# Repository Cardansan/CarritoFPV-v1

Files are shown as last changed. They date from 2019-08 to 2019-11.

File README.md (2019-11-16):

# CarritoFPV-v1
## ESP-8266
Usado para controlar los motores gracias al shield de NodeMCU. Éste es el Punto de Acceso WiFI, el ESP32 se conecta también aquí. IMPORTANTE: el shield es compatible con la tarjeta V2 (ESP-12E o NodeMCU 1.0).

Shield + ESP: https://articulo.mercadolibre.com.mx/MLM-702378293-modulos-shield-expansion-io-motores-puente-h-l293d-nodemcu-_JM

ESP: https://articulo.mercadolibre.com.mx/MLM-588747283-modulo-nodemcu-lua-wifi-esp8266-v2-cdmex-_JM?quantity=1

Shield: https://articulo.mercadolibre.com.mx/MLM-590470210-shield-expansion-io-motores-puente-h-l293d-nodemcu-esp8266-_JM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

## ESP32-CAM
https://articulo.mercadolibre.com.mx/MLM-671140521-esp32cam-modulo-esp32-cam-camara-ov2640-arduino-wifi-ble-_JM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

Hubieron detalles subiendo el código desde Platformio, con el IDE de Arduino sucedió sin incidentes. Recordar conectar como en el enlace de tutorial de ejemplo y oprimir el botón de reset de la placa cuando sea necesario. 

Tutorial ejemplo: https://randomnerdtutorials.com/esp32-cam-video-streaming-web-server-camera-home-assistant/

Programar con Arduino como FTDI: https://www.youtube.com/watch?v=a_PxAT8M-58

Troubleshooting: https://randomnerdtutorials.com/esp32-cam-troubleshooting-guide/

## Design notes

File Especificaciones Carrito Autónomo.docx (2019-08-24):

# Carrito Autónomo

# Introducción

La estructura está formada por palitos de bambú (⌀3 mm) y conectores impresos en 3D (PLA).

Se utiliza la misma base del Carrito Autónomo pero con diferentes componentes electrónicos para funcionar como vehículo de radiocontrol y FPV (first person view).

The structure is made of bamboo sticks (⌀3 mm) and 3D printed parts (PLA).

Autonomous toy car

It's controlled by Node MCU 1.0 (aka ESP-12E Dev Kit). It uses an ultrasonic distance sensor (US-100) attached to a servo (SG-90) so it can detect obstacles on the sides. A second servo moves the front wheels and a steering wheel to give it a realistic look. The microcontroller is connected to ESP-12E Motor Shield, the shield drives two gear motors.

FPV toy car

The ultrasonic sensor is replaced by a mini camera, and a RC receiver is added. Speed, steering and camera position is controlled by a RC transmitter.

Se presentará en la Semana del Emprendedor 2018.

Se usará en el Curso de Mecatrónica 2018.

# Partes

## Lista resumida

11 Nylon-insert lock nuts M3

16 Flat washers M3 (⌀external 7 mm, ⌀internal 3.2 mm, thickness 0.5 mm)

13 Bolts M3 (various lengths)

4 Screw M2x10 (or similar)

4 Screw to mount servos
18 Bamboo sticks ⌀3 mm (various lengths)

2 Gear motors

2 Micro servos (SG90)

25 3D printed parts [Autonomous version]

26 3D printed parts [FPV version]

1 Ultrasonic distance sensor (US-100, 3.3 V) [Autonomous version]

1 Mini camera (Eachine TX02 NTSC) [FPV version]

1 NodeMCU

1 RC Receiver and transmitter [FPV version]

Cables

Cyanoacrylate

Piezas 18A y 18B son para diferentes tamaños de sensores ultrasónicos.

Piezas 21A y 21B son para diferentes alturas de la cámara.

Parts 18A and 18B are for different sizes of ultrasonic sensors.

Part 20 only used in FPV version.

Parts 21A and 21B are for different camera heights.

## Longitudes de palitos

2x 15 mm

2x 70 mm

1x 80 mm

7x 90 mm

2x 100 mm

2x 130 mm

2x 180 mm

## Longitudes de tornillos

4x Bolt M3 x 15

4x Bolt M3 x 30

3x Bolt M3 x 20 ___

2x Bolt M3 x 5

4x Screw to mount servos (they come with SG90 servos)

4x Screw M2x10 (they hold horns to servos and wheels to gear motors)

## ESP-12E DevKit V2

También llamado NodeMCU 1.0

Al programar con Arduino IDE, es más fácil utilizar utilizar los nombres de pines D1 a D8

https://iotbytes.wordpress.com/nodemcu-pinout/

https://www.teachmemicro.com/nodemcu-pinout/

PWM con 1023 valores.

## ESP-12E Motor Shield

Utiliza el controlador L293DD

## Sensor de distancia ultrasónico US-100

Voltaje de alimentación 2.4V - 5.5V

Dos modos de funcionamiento: Serial y Pulso

El modo se selecciona con un jumper.

En modo Serial envía la lectura de distancia en formato de 2 bytes. En este modo también puede medir temperatura.

En modo Pulso envía un pulso con ancho proporcional a la distancia (como el HC-SR04).

En las pruebas realizadas la distancia máxima medible es 2 m (¿se puede configurar?)

https://www.bananarobotics.com/shop/US-100-Ultrasonic-Distance-Sensor-Module

http://tinkbox.ph/sites/mytinkbox.com/files/downloads/US_100_ULTRASONIC_SENSOR_MODULE.pdf

## Servomotor SG90

Servomotor muy popular. Marca TENSTAR ROBOT.

# Cómo programar ESP-12E con Arduino IDE

## Instalar Núcleo

Abrir Arduino IDE

Menú File → Preferences

Escribir la siguiente dirección en “Additional Boards Manager URLs”

http://arduino.esp8266.com/stable/package_esp8266com_index.json

Menú Tools → Board → Boards Manager

Escribe “esp” en el cuadro de búsqueda

Instala “esp8266 by ESP8266 Community”

Documentación: https://arduino-esp8266.readthedocs.io/en/latest/index.html

## Pinout

Se puede usar el número de GPIO en el código, pero es más fácil usar el nombre que aparece impreso en la placa (D0, D1, D2, …)

https://iotbytes.wordpress.com/nodemcu-pinout/

## PWM

Por defecto las salidas PWM pueden usar ciclos de trabajo de 0 a 1023.

Se puede configurar la frecuencia de PWM (1 a 1000 kHz) y el rango de ciclo de trabajo.

http://www.electronicwings.com/nodemcu/nodemcu-pwm-with-arduino-ide

# Versión modificada

Con cámara y receptor RC (radio-control).

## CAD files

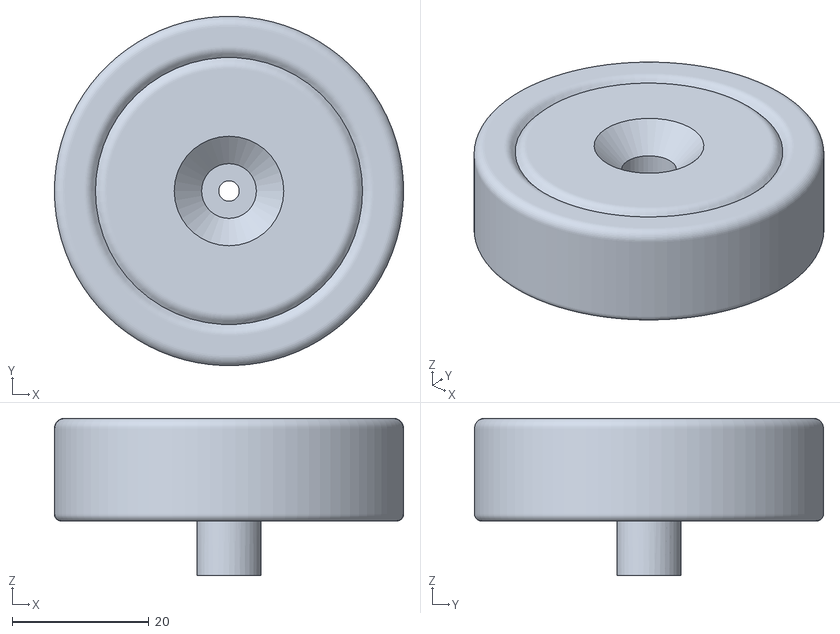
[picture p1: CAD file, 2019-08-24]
Piezas Impresión 3D/Filamento Flexible/13.STL
51.0 x 51.0 x 23.0

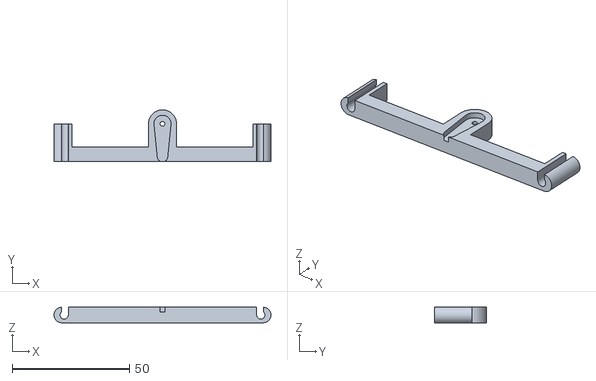
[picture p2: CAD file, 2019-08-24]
Piezas Impresión 3D/Imprimir Blanco/20.STL
92.7 x 22.0 x 6.70

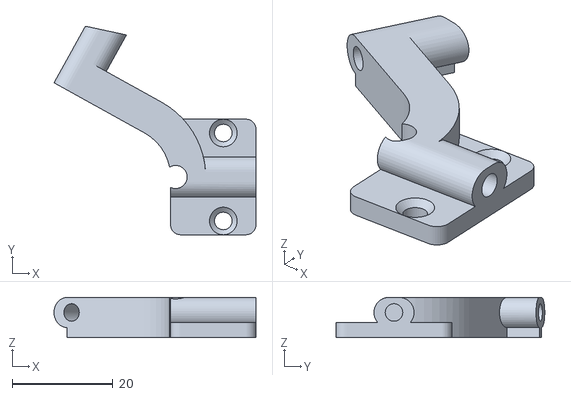
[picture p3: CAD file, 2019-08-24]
Piezas Impresión 3D/Imprimir Negro/1R.STL
40.2 x 41.5 x 8.00

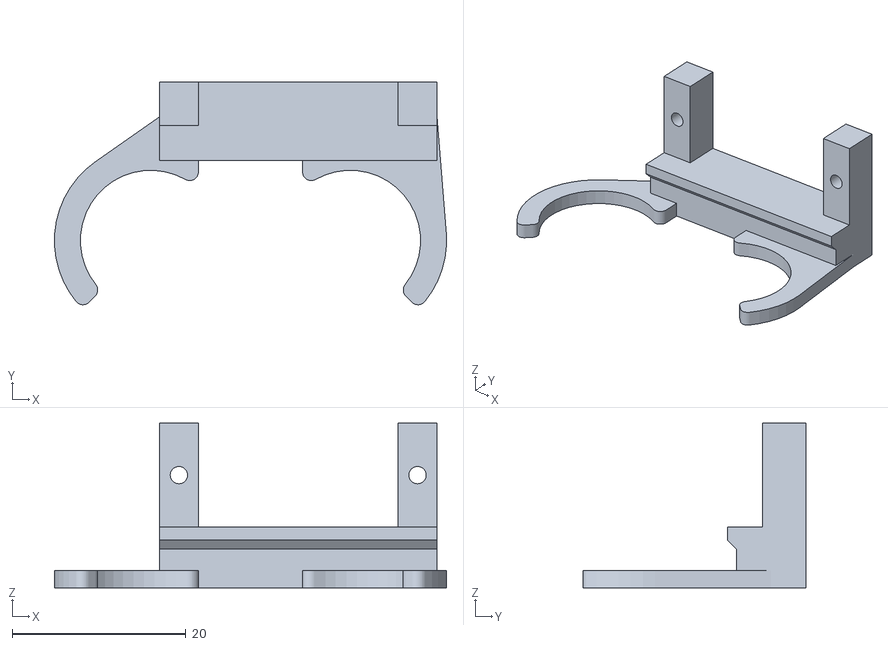
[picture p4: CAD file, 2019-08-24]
Piezas Impresión 3D/Imprimir Negro/Éstas aún no imprimir/18B.STL
45.2 x 25.6 x 19.0

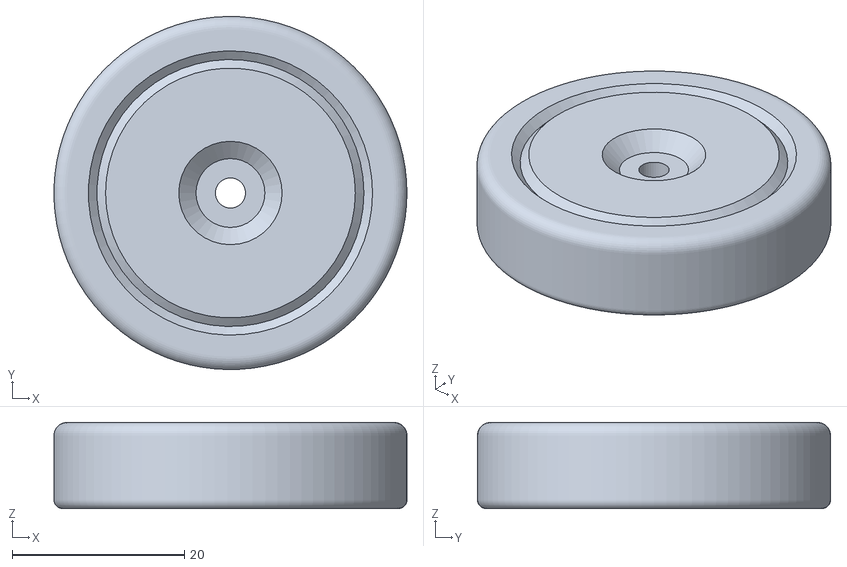
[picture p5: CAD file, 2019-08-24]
Piezas Impresión 3D/Filamento Flexible/12.STL
41.0 x 41.0 x 10.0

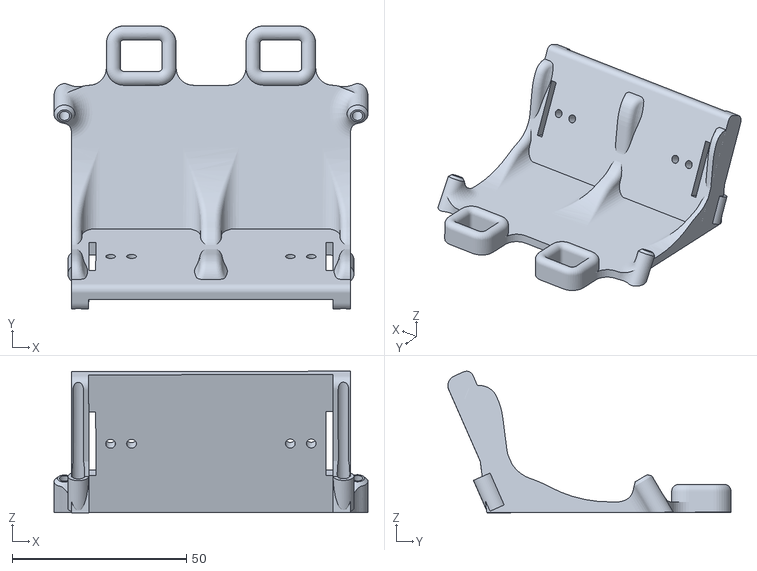
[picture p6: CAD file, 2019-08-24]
Piezas Impresión 3D/Imprimir Blanco/2.STL
90.0 x 81.1 x 40.6

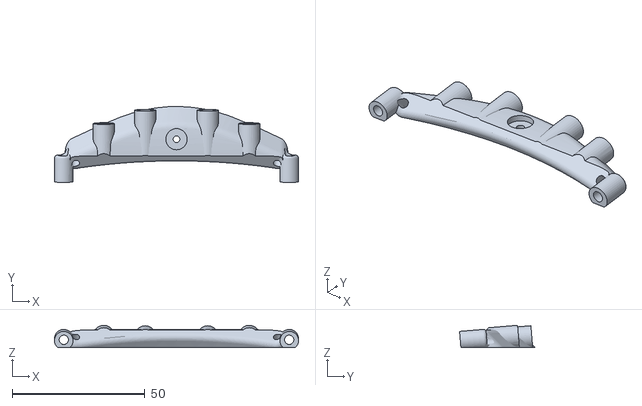
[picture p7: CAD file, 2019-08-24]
Piezas Impresión 3D/Imprimir Negro/5.STL
92.0 x 28.6 x 8.47

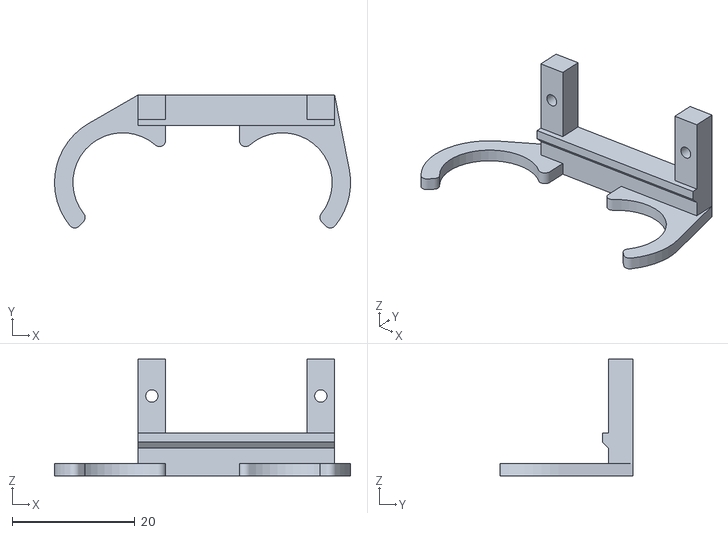
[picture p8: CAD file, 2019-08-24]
Piezas Impresión 3D/Imprimir Negro/Éstas aún no imprimir/18A.STL
48.2 x 21.6 x 19.0

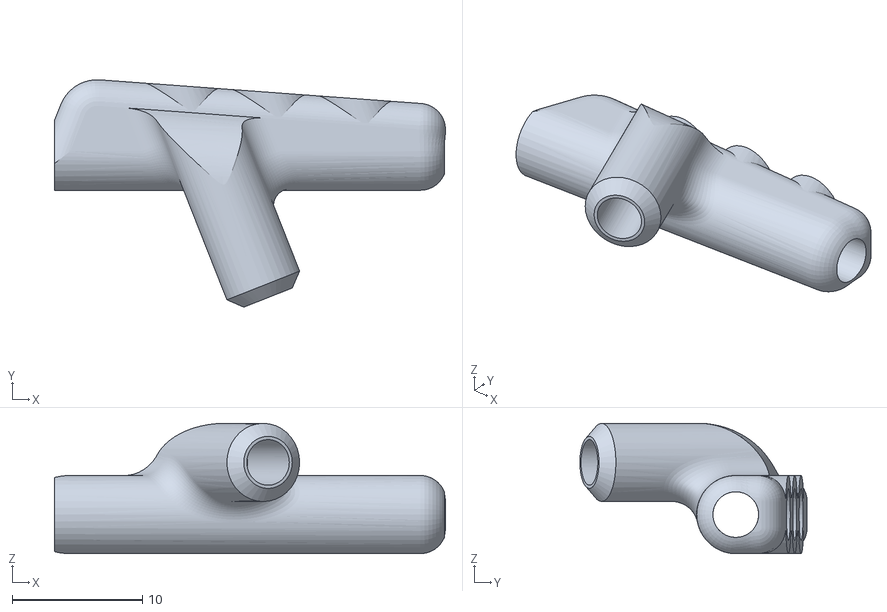
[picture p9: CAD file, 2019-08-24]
Piezas Impresión 3D/Imprimir Negro/3.STL
30.0 x 17.4 x 10.0

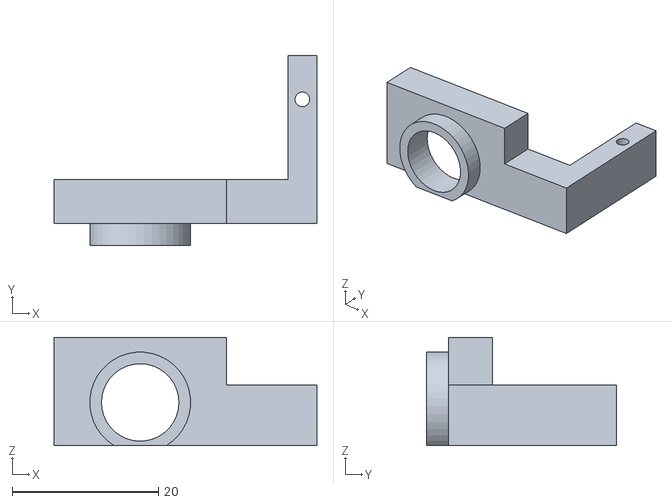
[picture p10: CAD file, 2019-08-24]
Piezas Impresión 3D/Imprimir Negro/Éstas aún no imprimir/21A.STL
36.0 x 26.0 x 14.8

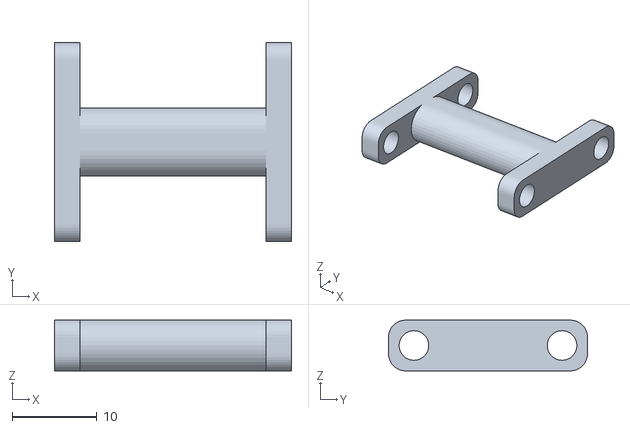
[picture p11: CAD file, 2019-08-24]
Piezas Impresión 3D/Imprimir Negro/0.STL
28.0 x 23.5 x 6.00

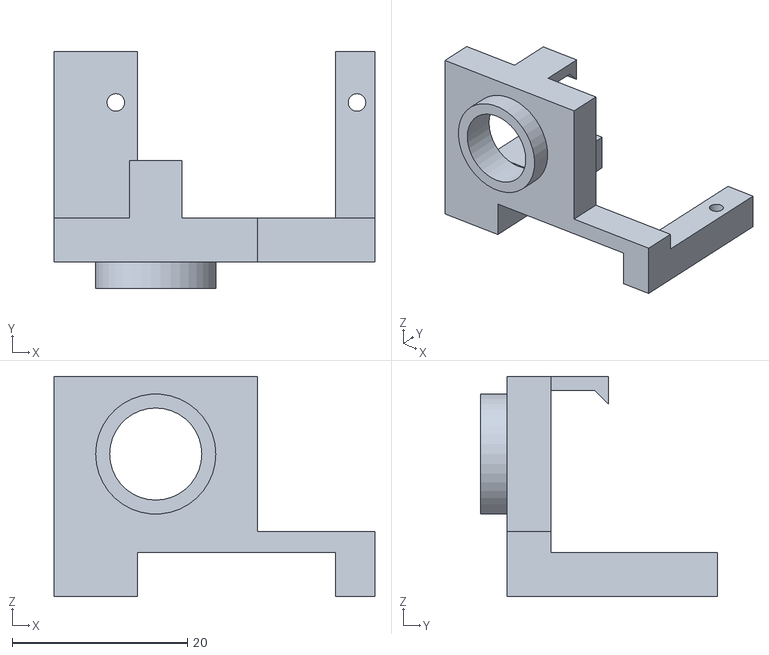
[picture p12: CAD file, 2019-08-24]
Piezas Impresión 3D/Imprimir Negro/Éstas aún no imprimir/21B.STL
36.6 x 27.0 x 25.1

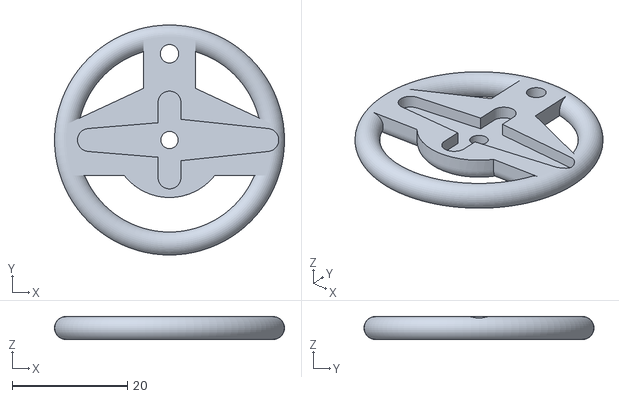
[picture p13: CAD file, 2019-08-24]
Piezas Impresión 3D/Imprimir Negro/17.STL
40.0 x 40.0 x 4.00

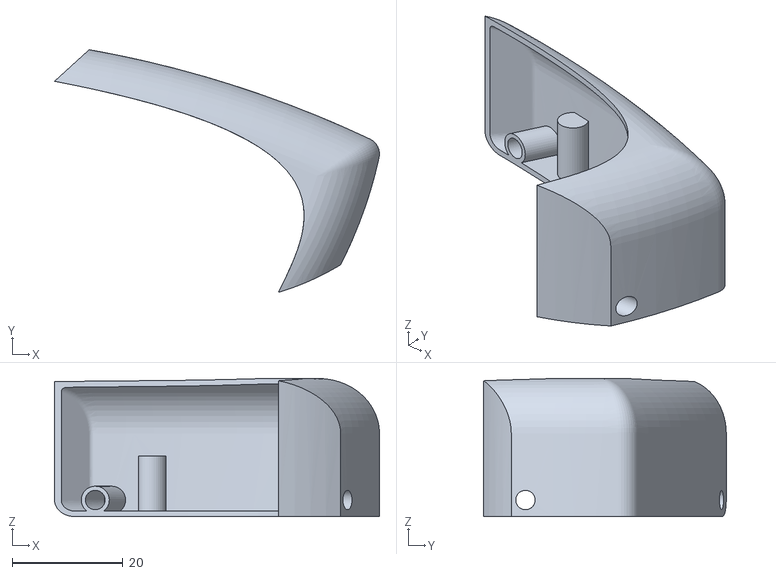
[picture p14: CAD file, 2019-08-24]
Piezas Impresión 3D/Imprimir Negro/8.STL
58.8 x 43.9 x 25.0

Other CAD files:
Piezas Impresión 3D/Imprimir Negro/4.STL
Piezas Impresión 3D/Imprimir Negro/14.STL
Piezas Impresión 3D/Imprimir Negro/1L.STL
Piezas Impresión 3D/Imprimir Negro/9.STL
Piezas Impresión 3D/Imprimir Negro/10.STL
Piezas Impresión 3D/Imprimir Negro/19.STL
Piezas Impresión 3D/Imprimir Negro/6.STL
Piezas Impresión 3D/Imprimir Negro/7.STL

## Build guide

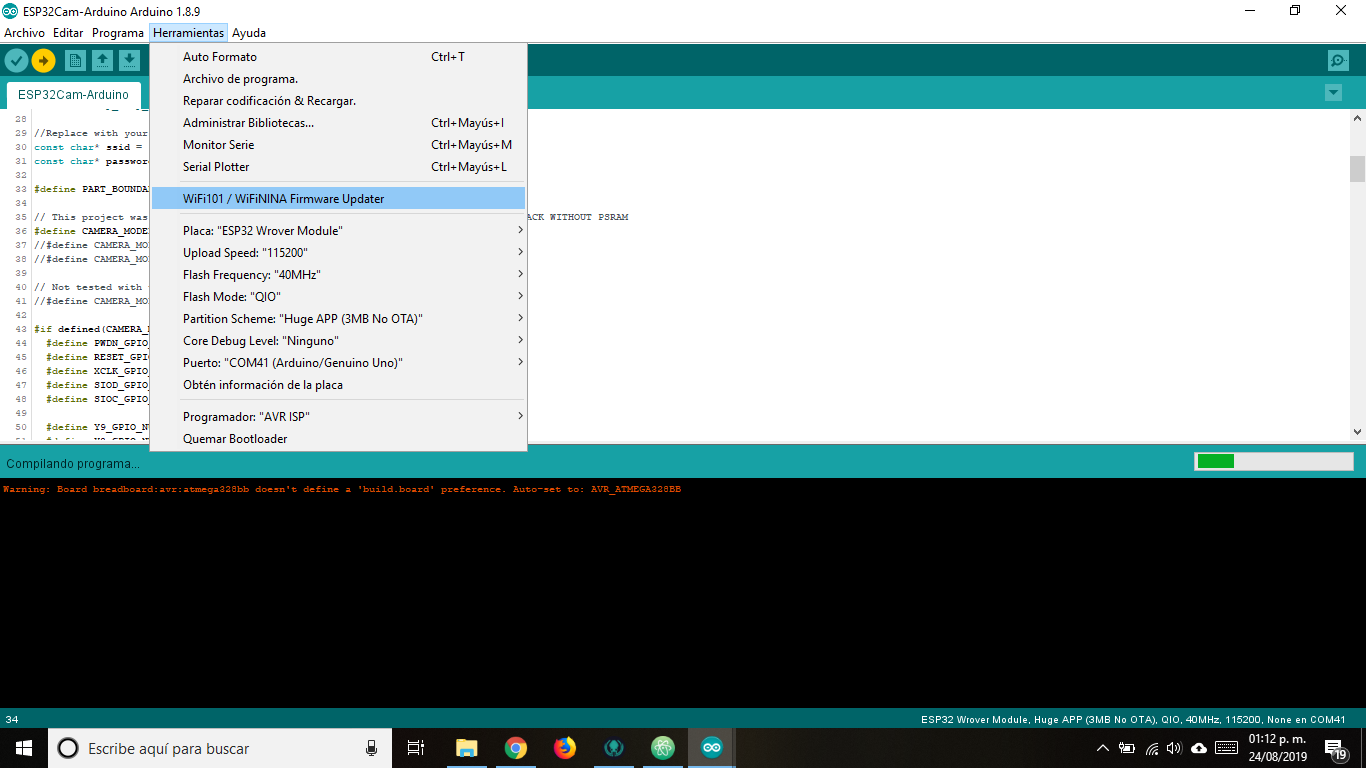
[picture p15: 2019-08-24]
ESP32CAMsetup.png

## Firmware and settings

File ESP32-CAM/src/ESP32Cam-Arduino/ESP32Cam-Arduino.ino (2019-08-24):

/*********
  Rui Santos
  Complete project details at https://RandomNerdTutorials.com
  
  IMPORTANT!!! 
   - Select Board "ESP32 Wrover Module"
   - Select the Partion Scheme "Huge APP (3MB No OTA)
   - GPIO 0 must be connected to GND to upload a sketch
   - After connecting GPIO 0 to GND, press the ESP32-CAM on-board RESET button to put your board in flashing mode
  
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
  The above copyright notice and this permission notice shall be included in all
  copies or substantial portions of the Software.
*********/

#include "esp_camera.h"
#include <WiFi.h>
#include "esp_timer.h"
#include "img_converters.h"
#include "Arduino.h"
#include "fb_gfx.h"
#include "soc/soc.h" //disable brownout problems
#include "soc/rtc_cntl_reg.h"  //disable brownout problems
#include "dl_lib.h"
#include "esp_http_server.h"

//Replace with your network credentials
const char* ssid = "CarroFPV";
const char* password = "science_7425";

#define PART_BOUNDARY "123456789000000000000987654321"

// This project was tested with the AI Thinker Model, M5STACK PSRAM Model and M5STACK WITHOUT PSRAM
#define CAMERA_MODEL_AI_THINKER
//#define CAMERA_MODEL_M5STACK_PSRAM
//#define CAMERA_MODEL_M5STACK_WITHOUT_PSRAM

// Not tested with this model
//#define CAMERA_MODEL_WROVER_KIT

#if defined(CAMERA_MODEL_WROVER_KIT)
  #define PWDN_GPIO_NUM    -1
  #define RESET_GPIO_NUM   -1
  #define XCLK_GPIO_NUM    21
  #define SIOD_GPIO_NUM    26
  #define SIOC_GPIO_NUM    27
  
  #define Y9_GPIO_NUM      35
  #define Y8_GPIO_NUM      34
  #define Y7_GPIO_NUM      39
  #define Y6_GPIO_NUM      36
  #define Y5_GPIO_NUM      19
  #define Y4_GPIO_NUM      18
  #define Y3_GPIO_NUM       5
  #define Y2_GPIO_NUM       4
  #define VSYNC_GPIO_NUM   25
  #define HREF_GPIO_NUM    23
  #define PCLK_GPIO_NUM    22

#elif defined(CAMERA_MODEL_M5STACK_PSRAM)
  #define PWDN_GPIO_NUM     -1
  #define RESET_GPIO_NUM    15
  #define XCLK_GPIO_NUM     27
  #define SIOD_GPIO_NUM     25
  #define SIOC_GPIO_NUM     23
  
  #define Y9_GPIO_NUM       19
  #define Y8_GPIO_NUM       36
  #define Y7_GPIO_NUM       18
  #define Y6_GPIO_NUM       39
  #define Y5_GPIO_NUM        5
  #define Y4_GPIO_NUM       34
  #define Y3_GPIO_NUM       35
  #define Y2_GPIO_NUM       32
  #define VSYNC_GPIO_NUM    22
  #define HREF_GPIO_NUM     26
  #define PCLK_GPIO_NUM     21

#elif defined(CAMERA_MODEL_M5STACK_WITHOUT_PSRAM)
  #define PWDN_GPIO_NUM     -1
  #define RESET_GPIO_NUM    15
  #define XCLK_GPIO_NUM     27
  #define SIOD_GPIO_NUM     25
  #define SIOC_GPIO_NUM     23
  
  #define Y9_GPIO_NUM       19
  #define Y8_GPIO_NUM       36
  #define Y7_GPIO_NUM       18
  #define Y6_GPIO_NUM       39
  #define Y5_GPIO_NUM        5
  #define Y4_GPIO_NUM       34
  #define Y3_GPIO_NUM       35
  #define Y2_GPIO_NUM       17
  #define VSYNC_GPIO_NUM    22
  #define HREF_GPIO_NUM     26
  #define PCLK_GPIO_NUM     21

#elif defined(CAMERA_MODEL_AI_THINKER)
  #define PWDN_GPIO_NUM     32
  #define RESET_GPIO_NUM    -1
  #define XCLK_GPIO_NUM      0
  #define SIOD_GPIO_NUM     26
  #define SIOC_GPIO_NUM     27
  
  #define Y9_GPIO_NUM       35
  #define Y8_GPIO_NUM       34
  #define Y7_GPIO_NUM       39
  #define Y6_GPIO_NUM       36
  #define Y5_GPIO_NUM       21
  #define Y4_GPIO_NUM       19
  #define Y3_GPIO_NUM       18
  #define Y2_GPIO_NUM        5
  #define VSYNC_GPIO_NUM    25
  #define HREF_GPIO_NUM     23
  #define PCLK_GPIO_NUM     22
#else
  #error "Camera model not selected"
#endif

static const char* _STREAM_CONTENT_TYPE = "multipart/x-mixed-replace;boundary=" PART_BOUNDARY;
static const char* _STREAM_BOUNDARY = "\r\n--" PART_BOUNDARY "\r\n";
static const char* _STREAM_PART = "Content-Type: image/jpeg\r\nContent-Length: %u\r\n\r\n";

httpd_handle_t stream_httpd = NULL;

static esp_err_t stream_handler(httpd_req_t *req){
  camera_fb_t * fb = NULL;
  esp_err_t res = ESP_OK;
  size_t _jpg_buf_len = 0;
  uint8_t * _jpg_buf = NULL;
  char * part_buf[64];

  res = httpd_resp_set_type(req, _STREAM_CONTENT_TYPE);
  if(res != ESP_OK){
    return res;
  }

  while(true){
    fb = esp_camera_fb_get();
    if (!fb) {
      Serial.println("Camera capture failed");
      res = ESP_FAIL;
    } else {
      if(fb->width > 400){
        if(fb->format != PIXFORMAT_JPEG){
          bool jpeg_converted = frame2jpg(fb, 80, &_jpg_buf, &_jpg_buf_len);
          esp_camera_fb_return(fb);
          fb = NULL;
          if(!jpeg_converted){
            Serial.println("JPEG compression failed");
            res = ESP_FAIL;
          }
        } else {
          _jpg_buf_len = fb->len;
          _jpg_buf = fb->buf;
        }
      }
    }
    if(res == ESP_OK){
      size_t hlen = snprintf((char *)part_buf, 64, _STREAM_PART, _jpg_buf_len);
      res = httpd_resp_send_chunk(req, (const char *)part_buf, hlen);
    }
    if(res == ESP_OK){
      res = httpd_resp_send_chunk(req, (const char *)_jpg_buf, _jpg_buf_len);
    }
    if(res == ESP_OK){
      res = httpd_resp_send_chunk(req, _STREAM_BOUNDARY, strlen(_STREAM_BOUNDARY));
    }
    if(fb){
      esp_camera_fb_return(fb);
      fb = NULL;
      _jpg_buf = NULL;
    } else if(_jpg_buf){
      free(_jpg_buf);
      _jpg_buf = NULL;
    }
    if(res != ESP_OK){
      break;
    }
    //Serial.printf("MJPG: %uB\n",(uint32_t)(_jpg_buf_len));
  }
  return res;
}

void startCameraServer(){
  httpd_config_t config = HTTPD_DEFAULT_CONFIG();
  config.server_port = 80;

  httpd_uri_t index_uri = {
    .uri       = "/",
    .method    = HTTP_GET,
    .handler   = stream_handler,
    .user_ctx  = NULL
  };
  
  //Serial.printf("Starting web server on port: '%d'\n", config.server_port);
  if (httpd_start(&stream_httpd, &config) == ESP_OK) {
    httpd_register_uri_handler(stream_httpd, &index_uri);
  }
}

void setup() {
  WRITE_PERI_REG(RTC_CNTL_BROWN_OUT_REG, 0); //disable brownout detector
 
  Serial.begin(115200);
  Serial.setDebugOutput(true);
  
  camera_config_t config;
  config.ledc_channel = LEDC_CHANNEL_0;
  config.ledc_timer = LEDC_TIMER_0;
  config.pin_d0 = Y2_GPIO_NUM;
  config.pin_d1 = Y3_GPIO_NUM;
  config.pin_d2 = Y4_GPIO_NUM;
  config.pin_d3 = Y5_GPIO_NUM;
  config.pin_d4 = Y6_GPIO_NUM;
  config.pin_d5 = Y7_GPIO_NUM;
  config.pin_d6 = Y8_GPIO_NUM;
  config.pin_d7 = Y9_GPIO_NUM;
  config.pin_xclk = XCLK_GPIO_NUM;
  config.pin_pclk = PCLK_GPIO_NUM;
  config.pin_vsync = VSYNC_GPIO_NUM;
  config.pin_href = HREF_GPIO_NUM;
  config.pin_sscb_sda = SIOD_GPIO_NUM;
  config.pin_sscb_scl = SIOC_GPIO_NUM;
  config.pin_pwdn = PWDN_GPIO_NUM;
  config.pin_reset = RESET_GPIO_NUM;
  config.xclk_freq_hz = 20000000;
  config.pixel_format = PIXFORMAT_JPEG; 
  
  if(psramFound()){
    config.frame_size = FRAMESIZE_UXGA;
    config.jpeg_quality = 10;
    config.fb_count = 2;
  } else {
    config.frame_size = FRAMESIZE_SVGA;
    config.jpeg_quality = 12;
    config.fb_count = 1;
  }
  
  // Camera init
  esp_err_t err = esp_camera_init(&config);
  if (err != ESP_OK) {
    Serial.printf("Camera init failed with error 0x%x", err);
    return;
  }
  // Wi-Fi connection
  WiFi.begin(ssid, password);
  while (WiFi.status() != WL_CONNECTED) {
    delay(500);
    Serial.print(".");
  }
  Serial.println("");
  Serial.println("WiFi connected");
  
  Serial.print("Camera Stream Ready! Go to: http://");
  Serial.print(WiFi.localIP());
  
  // Start streaming web server
  startCameraServer();
}

void loop() {
  delay(1);
}

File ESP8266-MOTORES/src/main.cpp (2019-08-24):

#include <ESP8266WiFi.h>
#include <ESP8266WebServer.h>

const char* ssid = "CarroFPV";
const char* password = "science_7425";

//------------------------------------------------------------ setupWiFi
void setupWiFi()
{
  WiFi.mode(WIFI_AP);
  WiFi.softAP(ssid, password);
  Serial.print("\n &IP Address: ");
  Serial.println(WiFi.softAPIP());
}

ESP8266WebServer server(80);

/*
#define PIN_PWMA D1 //motor derecho
#define PIN_DIRA D3
#define PIN_PWMB D2 //motor izquierdo
#define PIN_DIRB D4
*/

int PWMA=5;//Right side
int PWMB=4;//Left side
int DA=0;//Right reverse
int DB=2;//Left reverse

void handleRoot() {
  server.send(200, "text/plain", "For Car control go to '192.168.4.1/car'");
 }

void handleCar() {
 String message = "";
 int BtnValue = 0;
  for (uint8_t i = 0; i < server.args(); i++) {
    if (server.argName(i)=="a")
    {
      String s = server.arg(i);
      BtnValue = s.toInt();
    }
    Serial.println(server.argName(i) + ": " + server.arg(i) + "\n");
  }

  switch (BtnValue) {

   case 1: // Izquierda
    digitalWrite(PWMA, HIGH);
    digitalWrite(DA, LOW);
    digitalWrite(PWMB, LOW);
    digitalWrite(DB, LOW);
    break;
   case 2: // De frente
      digitalWrite(PWMA, HIGH);
      digitalWrite(DA, LOW);
      digitalWrite(PWMB, HIGH);
      digitalWrite(DB, LOW);
     break;
  case  3:// Derecha
     digitalWrite(PWMA, LOW);
     digitalWrite(DA, LOW);
     digitalWrite(PWMB, HIGH);
     digitalWrite(DB, LOW);
     break;
  case  4:// Izquierda Cam
     //motorSpeed(900,LOW,HIGH,900,HIGH,LOW);
     break;
  case 5: // Stop
   digitalWrite(PWMA, LOW);
   digitalWrite(DA, LOW);
   digitalWrite(PWMB, LOW);
   digitalWrite(DB, LOW);
   break;
  case  6://  Derecha Cam
     //motorSpeed(900,HIGH,LOW,900,LOW,HIGH);
    break;
  case 7://Izquierda atrás
    digitalWrite(PWMA, HIGH);
    digitalWrite(DA, HIGH);
    digitalWrite(PWMB, LOW);
    digitalWrite(DB, LOW);
    break;
  case 8://Atrás
    digitalWrite(PWMA, HIGH);
    digitalWrite(DA, HIGH);
    digitalWrite(PWMB, HIGH);
    digitalWrite(DB, HIGH);
    break;
  case 9://Derecha atrás
    digitalWrite(PWMA, LOW);
    digitalWrite(DA, LOW);
    digitalWrite(PWMB, HIGH);
    digitalWrite(DB, HIGH);
    default:
    break;
  }

  message += "<html> <head> <title>Gungor yalcin</title><head>";
  message += "<body><center><h3>Wifi CarroFPV NodeMCU  Web Server</center></h1>";
  message += "<table> ";
  message += "<tr>";
  message += "<td><p><a href=\"/car?a=1\"><button style=\"width:320;height:500;font-size:500px;\" class=\"button\">\\</button></a></p> ";
  message += "<td><p><a href=\"/car?a=2\"><button style=\"width:320;height:500;font-size:500px;\" class=\"button\">^</button></a></p> ";
  message += "<td><p><a href=\"/car?a=3\"><button style=\"width:320;height:500;font-size:500px;\" class=\"button\">/</button></a></p> ";
  message += "<tr>";
  message += "<td><p><a href=\"/car?a=4\"><button style=\"width:320;height:500;font-size:500px;\" class=\"button\"> < </button></a></p> ";
  message += "<td><p><a href=\"/car?a=5\"><button style=\"width:320;height:500;font-size:300px;\" class=\"button\">O</button></a></p> ";
  message += "<td><p><a href=\"/car?a=6\"><button style=\"width:320;height:500;font-size:500px;\" class=\"button\"> > </button></a></p> ";
  message += "<tr>";
  message += "<td><p><a href=\"/car?a=7\"><button style=\"width:320;height:500;font-size:500px;\" class=\"button\">/</button></a></p> ";
  message += "<td><p><a href=\"/car?a=8\"><button style=\"width:320;height:500;font-size:500px;\" class=\"button\">v</button></a></p> ";
  message += "<td><p><a href=\"/car?a=9\"><button style=\"width:320;height:500;font-size:500px;\" class=\"button\">\\</button></a></p> ";
  message += "</table> ";
  message += "</body></html>";
  server.send(200, "text/html", message);
 }

void handleNotFound() {
  String message = "File Not Found\n\n";
  message += "URI: ";
  message += server.uri();
  message += "\nMethod: ";
  message += (server.method() == HTTP_GET) ? "GET" : "POST";
  message += "\nArguments: ";
  message += server.args();
  message += "\n";
  for (uint8_t i = 0; i < server.args(); i++) {
    message += " " + server.argName(i) + ": " + server.arg(i) + "\n";
  }
  server.send(404, "text/plain", message);
}

void setup() {

pinMode(PWMA, OUTPUT);
pinMode(PWMB, OUTPUT); 
pinMode(DA, OUTPUT);
pinMode(DB, OUTPUT);

  Serial.begin(115200);

  setupWiFi();

  server.on("/", handleRoot);
  server.on("/car", handleCar);

  server.onNotFound(handleNotFound);

  server.begin();
  Serial.println("HTTP server started");
  }

  void loop() {
    server.handleClient();
  }

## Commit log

2019-08-24 Más archivos
    [0.STL, 10.STL, 12.STL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]
2019-08-24 Setup en la IDE para el ESP32
